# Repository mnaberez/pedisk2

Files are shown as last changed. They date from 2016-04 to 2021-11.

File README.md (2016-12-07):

# PEDISK II

This repository holds reverse engineering work on the
[PEDISK II](http://mikenaberezny.com/hardware/pet-cbm/microtech-pedisk-ii/) from CGRS Microtech,
a floppy disk controller for Commodore PET/CBM computers.

## Files

 - `rom_e800.bin` is a binary dump of the EPROM.

 - `rom_e800.asm` is a disassembly of it.

## Assemble

The `.asm` files can be assembled with the
[ACME](http://www.esw-heim.tu-clausthal.de/~marco/smorbrod/acme/)
assembler:

    $ acme -v1 --outfile test.bin pedisk2.asm

It should assemble a binary that is identical to the original.

## Credits

- Lee Davison did the initial disassembly of the ROM.
- Jim Oldfield provided the 5.25" PEDISK disks from which the DOS code was
  recovered.
- Mike Naberezny disassembled the 5.25" DOS code, adapted it for 8", and wrote
  the image tools.
- Steve Hirsch provided help and formatted 8" disks used for early testing.
- Josh Bensadon reverse engineered the original PCB and made the schematic.
- Steve Gray made the replica PCB layout and had boards manufactured.
- Mike Stein built the replica and provided help and input throughout.
- Bill Goble, the original designer of the PEDISK, found and donated the
  original manuals, schematics, source code, and master disks.

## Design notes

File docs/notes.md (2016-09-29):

PEDISK II Notes
===============

Drive Selection
---------------

The drive can be exercised from BASIC without using any of the PEDISK II's
ROM routines.  This is done by `POKE` and `PEEK` commands directly accessing
the FD1793 and the 74LS175 latch.  The drive must be selected before most
other commands will work.  

Select the first drive (drive 1):

    poke 59648,9 : rem write to $e900 latch (u7 74ls175)
                       bit 4 = fd1793 /dden (0=double density, 1=single)
                       bit 0 = drive 1 select

Deselect the drive:

    poke 59648,0

When the drive is selected, there will be an audible click as the head
load solenoid engages.  The activity LED on the front of the drive will
also turn on.  When deselected, the solenoid releases and the LED turns off.

Head Step
---------

Step out (decrease track, towards track 0):

    poke 59776,99 : rem write to $e980 fd1793 command register

Step in (increase track, towards track 76):

    poke 59776,67 : rem write to $e980 fd1793 command register

Do not step beyond track 76.  It will bump against the stop.

Random Seek
-----------

Restore (go to track 0):

    poke 59776,11 : rem write to $e980 fd1793 command register

Seek to a random track:

    poke 59779,t  : rem write to $e983 fd1793 data register
    poke 59776,27 : rem write to $e980 fd1793 command register

Show current track:

    print peek(59777) : rem read from $e981 fd1793 track register

Track Zero Sensor
-----------------

The track zero sensor is on pin 34 of the FD1793.  When the head is
positioned on track zero, pin 34 is low.  When it is not, pin 34
is high.

Bit 2 of the FD1793 status register is track zero status:

    print peek(59776) and 4 : rem read from $e980 fd1793 status register

Prints ``4`` when positioned on track zero, should print ``0``
when on any other track.

Write Protect Sensor
--------------------

The write protect sensor is on pin 36 of the FD1793.  When the notch is
covered, pin 36 is high.  When it is not, pin 36 is low.

Bit 6 of the FD1793 status register is write protect status:

    print peek(59776) and 64 : rem read from $e980 fd1793 status register

Prints ``64`` when notch is not covered, ``0`` when not is covered.

Index Hole Sensor
-----------------

The index hole sensor is on pin 35 of the FD1793.  When the drive is selected
(``sys 60320``) and a floppy is spinning, the line pulses.  When the drive
is not selected (``sys 60171``), or the floppy is not spinning, the line does
not pulse.

Disk Format
-----------

The PEDISK II model 877-1 uses an 8" single sided, soft sectored, single density
(FM) floppy disk. It has 77 tracks, 26 sectors per track, and a 128 byte sector
length.  It can hold about 250 KB.

8" double sided disks are not compatible because they have the index hole in
a different position than 8" single sided disks.  The PEDISK requires single
sided disks.  If a double sided disk is inserted, the index hole sensor will
not pulse, and the head load solenoid will not engage.

8" hard sectored disks are also not compatible.  The PEDISK requires soft
sectored disks.  If a hard sectored disk is inserted, the head load solenoid
will engage, but the format program will hang.

FD1793 pin 37 is ``/DDEN`` (``/DOUBLE DENSITY``) and should be low when double
density.  On the PEDISK II, pin 37 is high (single density).

FD1793 pin 24 is ``CLK`` (``CLOCK``).  According to the datasheet, it should
be 2.0 MHz for 8" drives.  On the PEDISK II, it measures 2.0 MHz on the
logic analyzer.

Midnite Software Gazette, Issue 11 (Feb/Mar 1983):
"PEDISK Model 877 is an 8" SD floppy disk system that uses the IBM 3740
 format ... Eight inch SD CPM (trademark of Digital Research) diskettes
 can also be read/written with the 877 system."

From the ROM:
 - Tracks: 77 ($EBD3)
 - Sectors Per Track: ($EC74)
 - Sector Length: 128 bytes ($ECCA)

Board Jumpers
-------------

Jumper W1 is ``8`` or ``5``.  This means 8" or 5.25".  When the jumpered
for ``8``, FD1793 pin 24 ``CLK`` measures 2.0 MHz on the logic analyzer.  When
jumpered for ``5``, ``CLK`` measures 1.0 MHz.  This matches what the datasheet
says ``CLK`` should be for 8" and 5.25" drives.

Jumper W2 is ``250`` or ``125``.  It is set to ``250``.  This is probably
the bit rate (kbits/sec).  For Single Density 8", the bit rate is 250
kbits/sec.  According to a [table](http://en.wikipedia.org/wiki/List_of_floppy_disk_formats),
all the 8" double density formats are 500 kbits/sec.  There is no
``500`` option on the PEDISK board.

Jumpers W3, W4, and W5 are unknown.  They are all open.

BASIC Wedge
-----------

Initialize the PEDISK II and it will attempt to load the DOS from disk:

    sys 59904

It should print the welcome banner:

    pedisk ii system
    cgrs microtech
    langhorne,pa.19047 c1981

After a short time, it will return to the ``ready.`` prompt.  If the DOS
can't be loaded from disk, a ``disk error`` message will be printed before
the prompt the prompt returns.  The BASIC wedge is not installed if the DOS
is not loaded.

Detect if the wedge is installed:

    print peek(121)

Prints ``76`` if installed or ``201`` if not installed.

All of the PEDISK II commands are loaded into RAM from the boot disk, with the
sole exception of ``!load``.  The ``!load`` command can be used even if the boot
disk can't be loaded.  However, the wedge must be force installed.

Force the wedge to install:

    sys 60159

Load a program:

    !load"foobar:0"

The filename (``foobar``) may be up to six characters.  The drive number
(``:0``) must be included or else a ``?syntax error`` will result.

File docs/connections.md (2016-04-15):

34-pin Floppy Drive Connector
-----------------------------

| PEDISK II 34-pin | 50-pin |Dir  |Siemens | Shugart | Micropolis | Notes |
|---:|---:|:---:|---:|---:|---:|:-----:|
| N/C | 2 | | | | | |
| N/C | 4 | | | | | |
| N/C | 6 | | | | | |
| N/C | 8 | | | | | |
| N/C | 10 | In  | 2SIDED | | | |
| N/C | 12 | Out | DCG | | | |
| N/C | 14 | Out | SIDE | | | |
| N/C | 16 | Out | IN USE | | | |
| N/C | 18 | Out | HLD | | | |
| 4 | 20 | In  | INDEX | (IN USE)| N/C | *1, 2*|
| 6 | 22 | In  | READY | SEL4 | READY | *3* |
| 8 | 24 | In  | (SECTOR) | INDEX | SEC/INDEX  | *1, 2*|
| 10 | 26 | Out | SEL1 | SEL1 | SEL1 | |
| 12 | 28 | Out | SEL2 | SEL2 | SEL2 | |
| N/C | 30 | Out | SEL3 | SEL3 | SEL3 | |
| 16 | 32 | Out | SEL4 | MOTOR | MOTOR | *4* |
| 18 | 34 | Out | DIRC | DIRC | DIRC | |
| 20 | 36 | Out | STEP | STEP | STEP | |
| 22 | 38 | Out | WDAT | WDAT | WDAT | |
| 24 | 40 | Out | WRITE | WGATE | WGATE | |
| 26 | 42 | In  | TRK00 | TRK00 | TRK00 | |
| 28 | 44 | In  | WPROT | WPROT | WPROT | |
| 30 | 46 | In  | RDATA | RDATA | RDATA | |
| 32 | 48 | Both| (SEP DAT)| HD SEL  | HD SEL | *1, 5*|
| N/C | 50 | In  | (SEP CLK)| RY/DC | SEL4 | *1* |

Notes:

1. `(XX)` is an optional signal that may not be installed on the drive.

2. PEDISK II always connects pins 4(20) and 8(24) in parallel.

3. PEDISK II is no-connect unless jumper W4 is installed.  If W4 is installed,
   the WD1793 gets the `READY` signal from the drive.

4. PEDISK II is no-connect unless jumper W3 is installed.  If W3 is installed,
   `MOTOR` is grounded (motor always on).

5. PEDISK II is no-connect unless jumper W5 is installed.  If W5 is installed,
   the PEDISK II can control `HD SEL` (Head Select).

Jumper Settings
---------------

| Jumper |5.25"  |8" | Description | Notes |
|---|---|---|---|:-----:|
| W1 250/125 |250 |250 | Select Bit Rate (kbits/sec) | |
| W2 5/8 |5 |8 | ??? | |
| W3 |Close  |Open | Grounds MOTOR | |
| W4 |Depends|Depends| Close for Micropolis drives with RDY | *1* |
| W5 |Close  |Open | Connects HD SELECT for 5.25" | &nbsp;|

Notes:

1. An 8" PEDISK II system was found with a Siemens FDD100-8 drive.  This drive
   has a `READY` signal on pin 6(22) but the PEDISK II was configured with W4
   open.  The system works in this configuration.

In addition to the jumpers above, the WD1793's `/DDEN` (Double Density Enable)
line must be set high for 8" (single density) or low for 5.25" (double
density).  `/DDEN` is controlled by pin 15 of the U7 latch.  The
firmware/software must be changed to set `/DDEN` appropriately.  Another option
would be to disconnect `/DDEN` from the latch and tie it permanently high
or low.

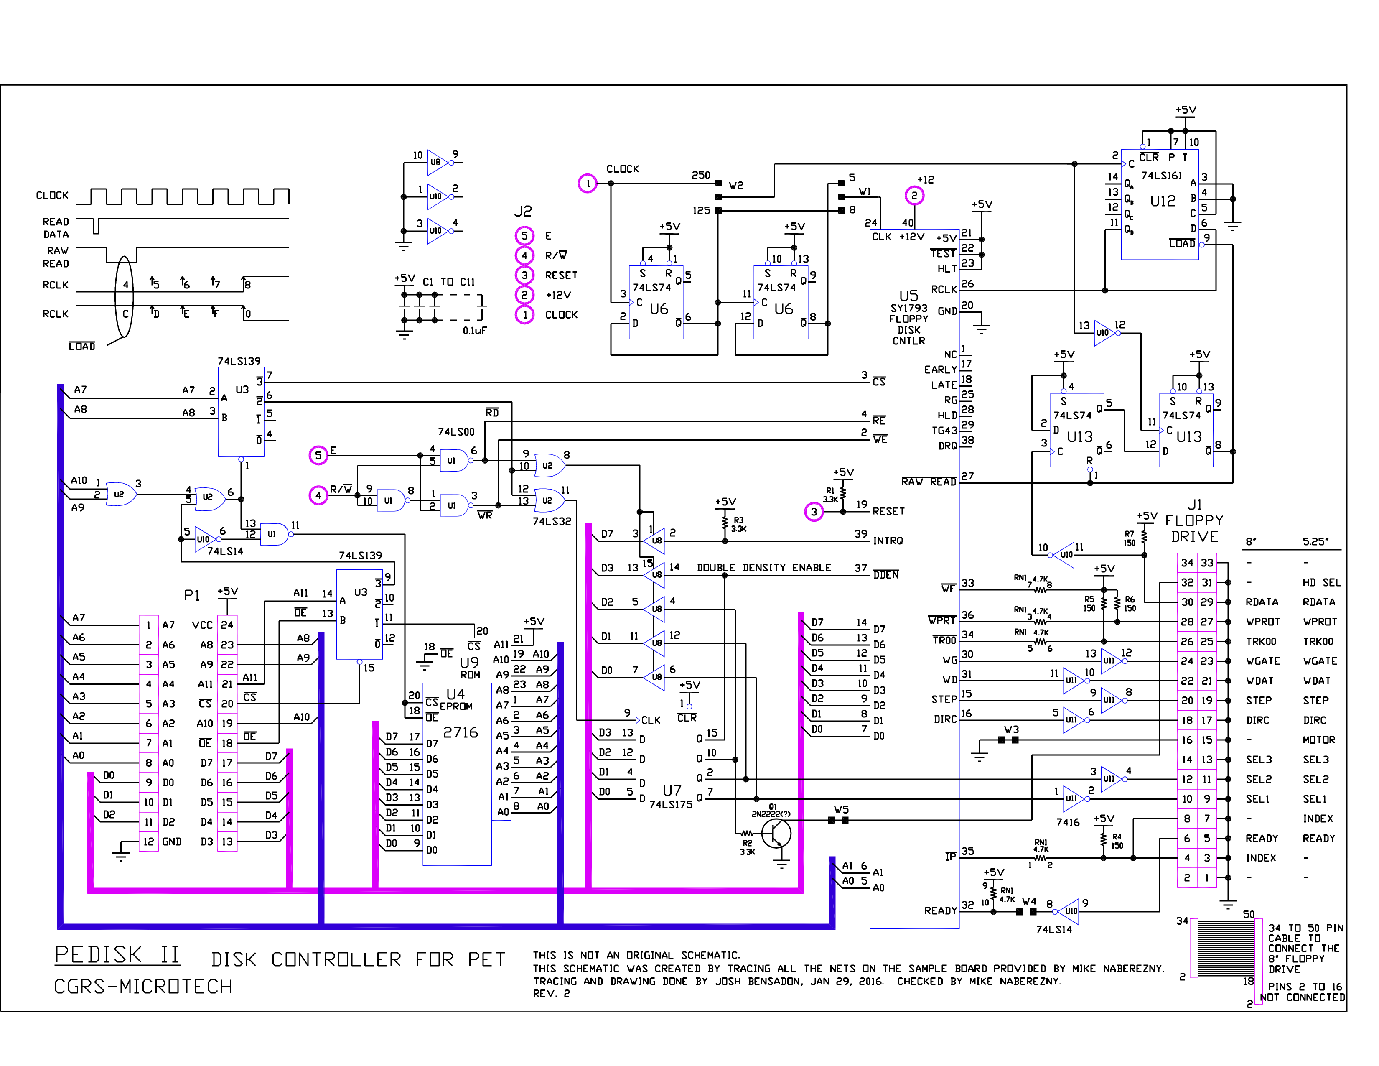
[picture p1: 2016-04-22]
docs/schematic.png

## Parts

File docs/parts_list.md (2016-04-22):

Parts List
----------

| Reference | Part |
|---|---|
| C1-11 | 0.1 uF |
| J1 | 34-pin Header |
| Q1 | 2N2222 (??) |
| R1, R2, R3, R7 | 3.3 K |
| R4, R5, R6 | 150 Ohm |
| RN1 | 4.7 K |
| U1 | 74LS00 |
| U2 | 74LS32 |
| U3 | 74LS139 |
| U4 | 2716 |
| U5 | WD1793 |
| U6 | 74LS74 |
| U7 | 74LS175 |
| U8 | 74367 |
| U9 | 901474-03 |
| U10 | 74LS14 |
| U11 | 7416 |
| U12 | 74LS161 |
| U13 | 74LS74 |
| W1, W2 | 3-pin Jumper Block |
| W3, W4, W5 | 2-pin Jumper Block |

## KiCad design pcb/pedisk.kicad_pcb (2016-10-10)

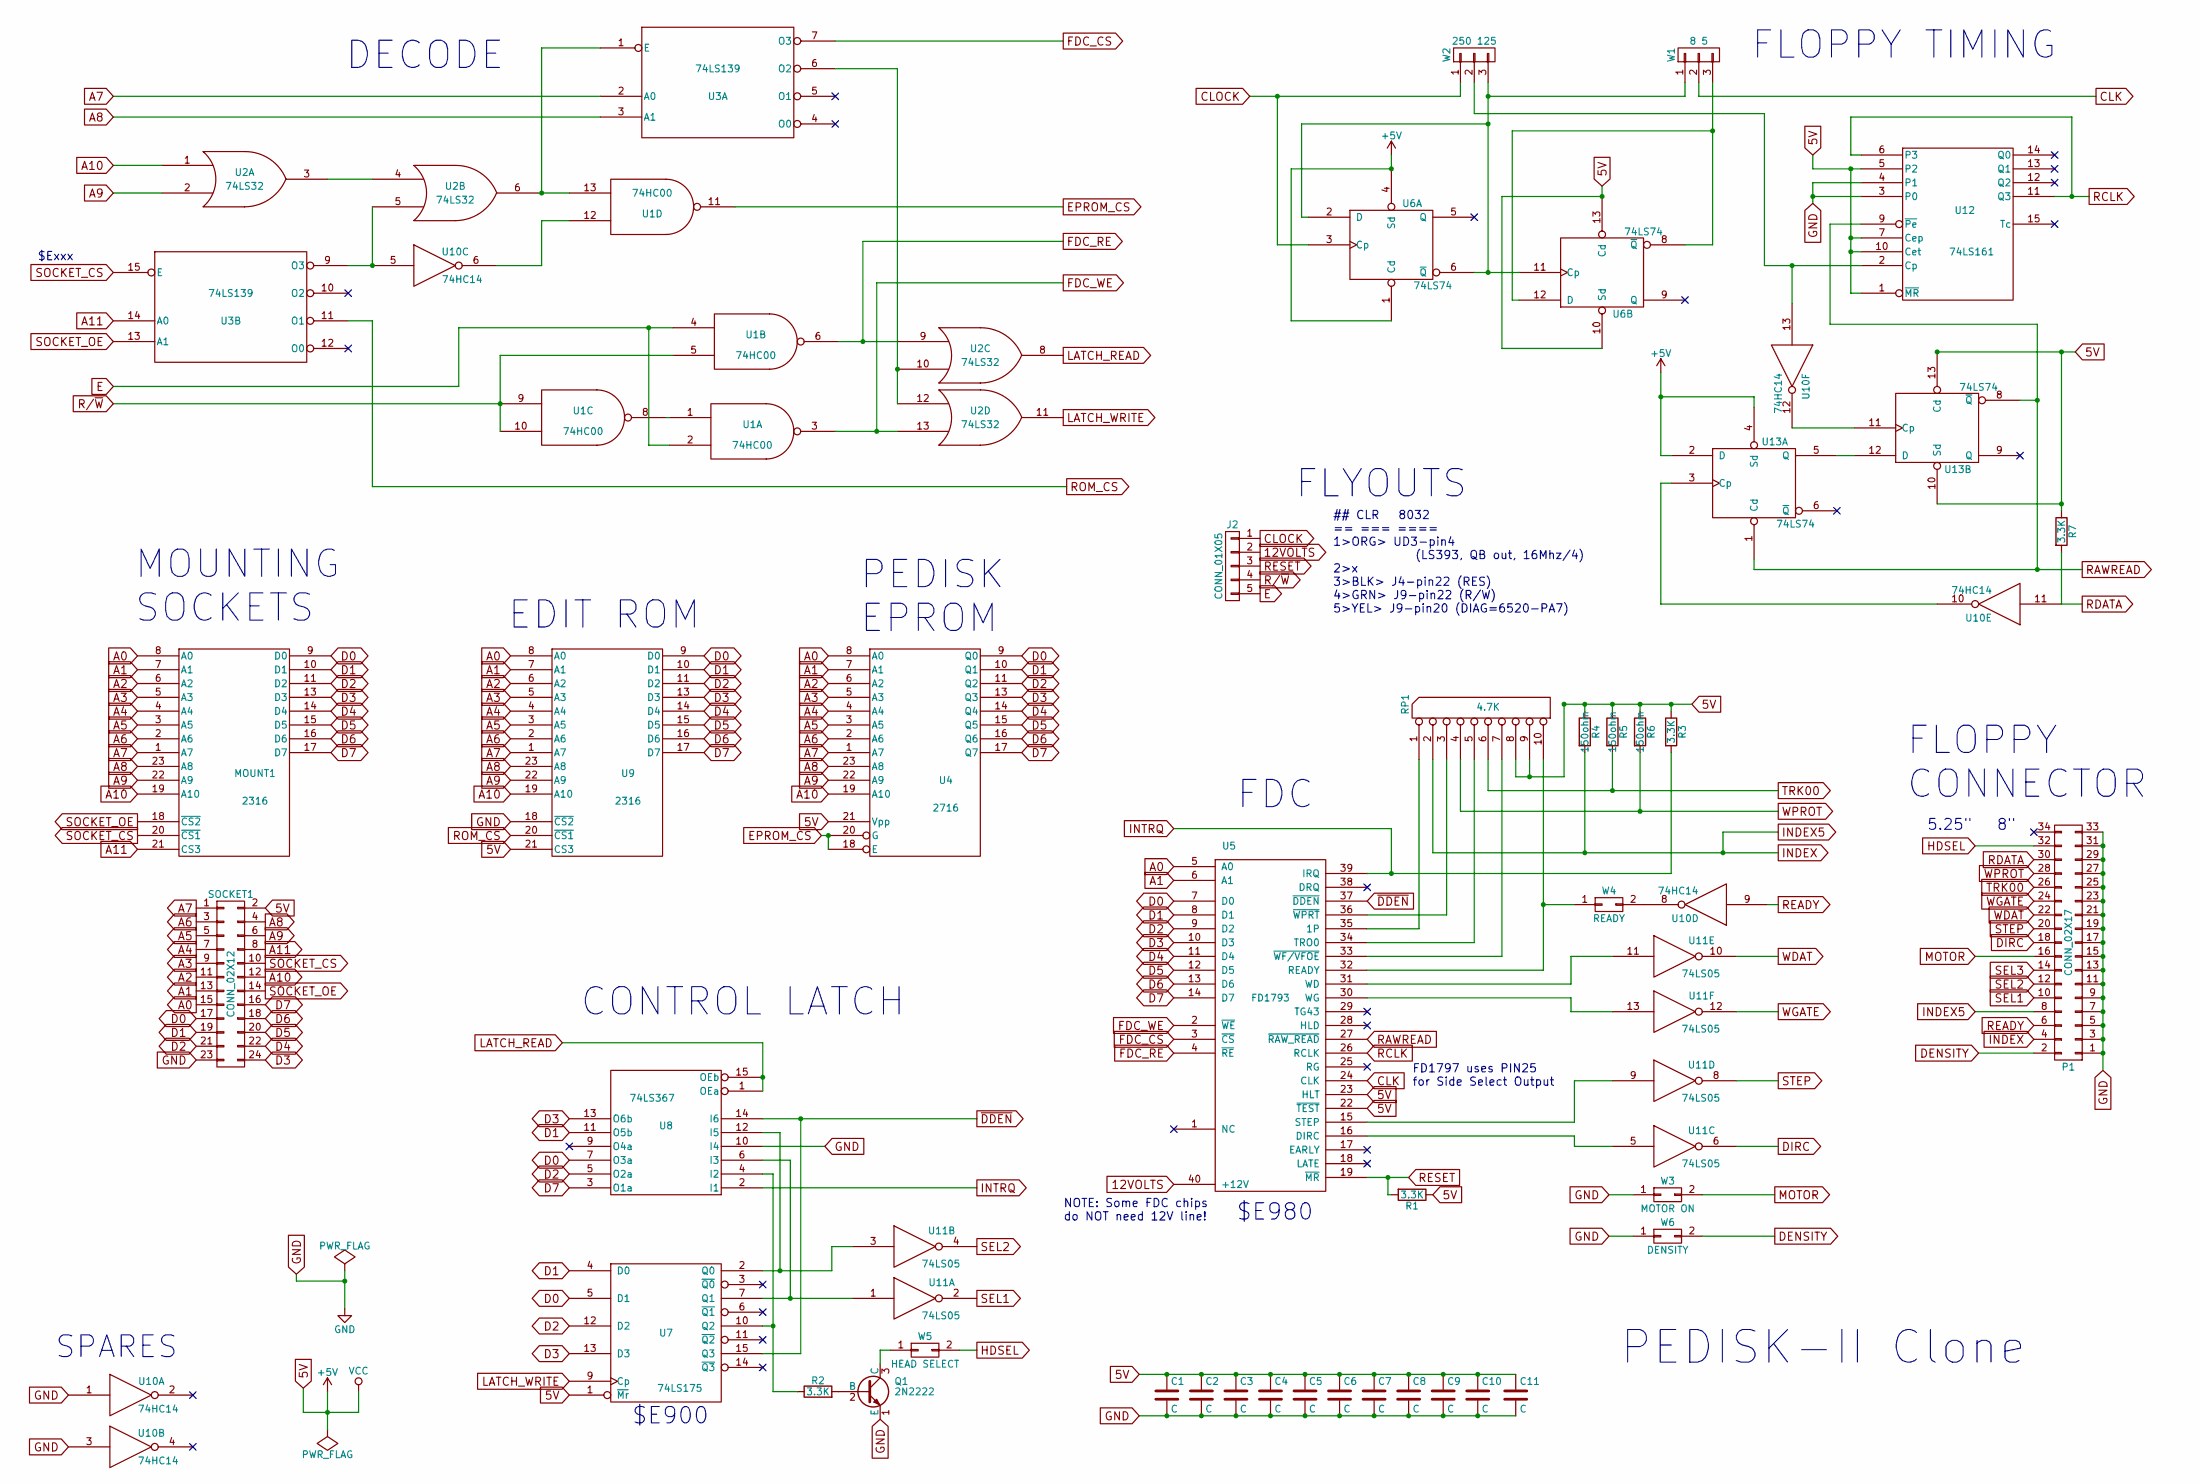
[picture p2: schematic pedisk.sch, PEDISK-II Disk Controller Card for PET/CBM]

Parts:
C1, C2, C3, C4, C5, C6, C7, C8, C9, C10, C11: C; C_Disc_D3_P2.5
J2: CONN_01X05; Pin_Header_Straight_1x05
MOUNT1: 2316; DIP-24_W15.24mm_LongPads
P1: CONN_02X17; IDC_Header_Straight_34pins
Q1: 2N2222; TO-92_Inline_Wide
R1, R2, R3, R7: 3.3K; Resistor_Horizontal_RM10mm
R4, R5, R6: 150ohm; Resistor_Horizontal_RM10mm
RP1: 4.7K; Resistor_Array_SIP9
SOCKET1: CONN_02X12; Pin_Header_Straight_2x12
U1: 74HC00; DIP-14_W7.62mm_LongPads
U2: 74LS32; DIP-14_W7.62mm_LongPads
U3: 74LS139; DIP-16_W7.62mm_LongPads
U4: 2716; DIP-24_W15.24mm_LongPads
U5: FD1793; DIP-40_W15.24mm_LongPads
U6, U13: 74LS74; DIP-14_W7.62mm_LongPads
U7: 74LS175; DIP-16_W7.62mm_LongPads
U8: 74LS367; DIP-16_W7.62mm_LongPads
U9: 2316; DIP-24_W15.24mm_LongPads
U10: 74HC14; DIP-14_W7.62mm_LongPads
U11: 74LS05; DIP-14_W7.62mm_LongPads
U12: 74LS161; DIP-16_W7.62mm_LongPads
W1: 8 5; Pin_Header_Straight_1x03
W2: 250 125; Pin_Header_Straight_1x03
W3: MOTOR ON; Pin_Header_Straight_2x01
W4: READY; Pin_Header_Straight_2x01
W5: HEAD SELECT; Pin_Header_Straight_2x01
W6: DENSITY; Pin_Header_Straight_2x01

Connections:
12VOLTS: J2.2, U5.40 (+12V)
A0: MOUNT1.8 (A0), SOCKET1.15, U4.8 (A0), U5.5 (A0), U9.8 (A0)
A1: MOUNT1.7 (A1), SOCKET1.13, U4.7 (A1), U5.6 (A1), U9.7 (A1)
A2: MOUNT1.6 (A2), SOCKET1.11, U4.6 (A2), U9.6 (A2)
A3: MOUNT1.5 (A3), SOCKET1.9, U4.5 (A3), U9.5 (A3)
A4: MOUNT1.4 (A4), SOCKET1.7, U4.4 (A4), U9.4 (A4)
A5: MOUNT1.3 (A5), SOCKET1.5, U4.3 (A5), U9.3 (A5)
A6: MOUNT1.2 (A6), SOCKET1.3, U4.2 (A6), U9.2 (A6)
A7: MOUNT1.1 (A7), SOCKET1.1, U3.2 (A0), U4.1 (A7), U9.1 (A7)
A8: MOUNT1.23 (A8), SOCKET1.4, U3.3 (A1), U4.23 (A8), U9.23 (A8)
A9: MOUNT1.22 (A9), SOCKET1.6, U2.2, U4.22 (A9), U9.22 (A9)
A10: MOUNT1.19 (A10), SOCKET1.12, U2.1, U4.19 (A10), U9.19 (A10)
A11: MOUNT1.21 (CS3), SOCKET1.8, U3.14 (A0)
CLK: U5.24 (CLK), W1.2
CLOCK: J2.1, U6.3 (Cp), W2.1
D0: MOUNT1.9 (D0), SOCKET1.17, U4.9 (Q0), U5.7 (D0), U7.5 (D1), U8.7 (O3a), U9.9 (D0)
D1: MOUNT1.10 (D1), SOCKET1.19, U4.10 (Q1), U5.8 (D1), U7.4 (D0), U8.11 (O5b), U9.10 (D1)
D2: MOUNT1.11 (D2), SOCKET1.21, U4.11 (Q2), U5.9 (D2), U7.12 (D2), U8.5 (O2a), U9.11 (D2)
D3: MOUNT1.13 (D3), SOCKET1.24, U4.13 (Q3), U5.10 (D3), U7.13 (D3), U8.13 (O6b), U9.13 (D3)
D4: MOUNT1.14 (D4), SOCKET1.22, U4.14 (Q4), U5.11 (D4), U9.14 (D4)
D5: MOUNT1.15 (D5), SOCKET1.20, U4.15 (Q5), U5.12 (D5), U9.15 (D5)
D6: MOUNT1.16 (D6), SOCKET1.18, U4.16 (Q6), U5.13 (D6), U9.16 (D6)
D7: MOUNT1.17 (D7), SOCKET1.16, U4.17 (Q7), U5.14 (D7), U8.3 (O1a), U9.17 (D7)
DENSITY: P1.2, W6.2
DIRC: P1.18, U11.6
E: J2.5, U1.2, U1.4
EPROM_CS: U1.11, U4.18 (E), U4.20 (G)
FDC_CS: U3.7 (O3), U5.3 (~CS)
FDC_RE: U1.6, U2.9, U5.4 (~RE)
FDC_WE: U1.3, U2.13, U5.2 (~WE)
GND: C1.2, C2.2, C3.2, C4.2, C5.2, C6.2, C7.2, C8.2, C9.2, C10.2, C11.2, MOUNT1.12 (GND), P1.1, P1.3, P1.5, P1.7, P1.9, P1.11, P1.13, P1.15, P1.17, P1.19, P1.21, P1.23, P1.25, P1.27, P1.29, P1.31, P1.33, Q1.1 (E), SOCKET1.23, U1.7 (GND), U2.7 (GND), U3.8 (GND), U4.12 (GND), U5.20 (GND), U6.7 (GND), U7.8 (GND), U8.8 (GND), U8.10 (I4), U9.12 (GND), U9.18 (~CS2), U10.1, U10.3, U10.7 (GND), U11.7 (GND), U12.3 (P0), U12.4 (P1), U12.8 (GND), U13.7 (GND), W3.1, W6.1
HDSEL: P1.32, W5.2
INDEX: P1.4, P1.8, R4.2, RP1.2
INTRQ: R3.2, U5.39 (IRQ), U8.2 (I1)
LATCH_READ: U2.8, U8.1 (OEa), U8.15 (OEb)
LATCH_WRITE: U2.11, U7.9 (Cp)
MOTOR: P1.16, W3.2
unnamed: Q1.2 (B), R2.2
unnamed: Q1.3 (C), W5.1
unnamed: R2.1, U7.10 (Q2), U8.4 (I2)
unnamed: RP1.1 (COM), U5.35 (1P)
unnamed: RP1.3, U5.36 (~WPRT)
unnamed: RP1.5, U5.34 (TRO0)
unnamed: RP1.7, U5.33 (~WF/VFOE)
unnamed: RP1.10, U5.32 (READY), W4.1
unnamed: U1.1, U1.8
unnamed: U1.12, U10.6
unnamed: U1.13, U2.6, U3.1 (E)
unnamed: U2.3, U2.4
unnamed: U2.10, U2.12, U3.6 (O2)
unnamed: U6.2 (D), U6.6 (~Q), U6.11 (Cp), W1.1, W2.3
unnamed: U6.8 (~Q), U6.12 (D), W1.3
unnamed: U2.5, U3.9 (O3), U10.5
unnamed: U10.8, W4.2
unnamed: U10.10, U13.3 (Cp)
unnamed: U10.12, U13.11 (Cp)
unnamed: U10.13, U12.2 (Cp), W2.2
unnamed: U7.7 (Q1), U8.6 (I3), U11.1
unnamed: U7.2 (Q0), U8.12 (I5), U11.3
unnamed: U5.16 (DIRC), U11.5
unnamed: U5.15 (STEP), U11.9
unnamed: U5.31 (WD), U11.11
unnamed: U5.30 (WG), U11.13
unnamed: U13.5 (Q), U13.12 (D)
R/~W: J2.4, U1.5, U1.9, U1.10
RAWREAD: U5.27 (~RAW_READ), U12.9 (~Pe), U13.1 (Cd), U13.8 (~Q)
RCLK: U5.26 (RCLK), U12.6 (P3), U12.11 (Q3)
RDATA: P1.30, R7.2, U10.11
READY: P1.6, U10.9
ROM_CS: U3.11 (O1), U9.20 (~CS1)
SEL1: P1.10, U11.2
SEL2: P1.12, U11.4
SEL3: P1.14
SOCKET_CS: MOUNT1.20 (~CS1), SOCKET1.10, U3.15 (E)
SOCKET_OE: MOUNT1.18 (~CS2), SOCKET1.14, U3.13 (A1)
STEP: P1.20, U11.8
TRK00: P1.26, R5.2, RP1.6
WDAT: P1.22, U11.10
WGATE: P1.24, U11.12
WPROT: P1.28, R6.2, RP1.4
~DDEN: U5.37 (~DDEN), U7.15 (Q3), U8.14 (I6)

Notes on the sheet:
SPARES
FLYOUTS
MOUNTING SOCKETS
PEDISK EPROM
EDIT ROM
DECODE
CONTROL LATCH
FDC
FLOPPY TIMING
FLOPPY CONNECTOR
PEDISK-II Clone
5.25" 8"
## CLR 8032 == === ==== 1>ORG> UD3-pin4 (LS393, QB out, 16Mhz/4) 2>x 3>BLK> J4-pin22 (RES) 4>GRN> J9-pin22 (R/W) 5>YEL> J9-pin20 (DIAG=6520-PA7)
$E980
$E900
$Exxx
NOTE: Some FDC chips do NOT need 12V line!
FD1797 uses PIN25 for Side Select Output

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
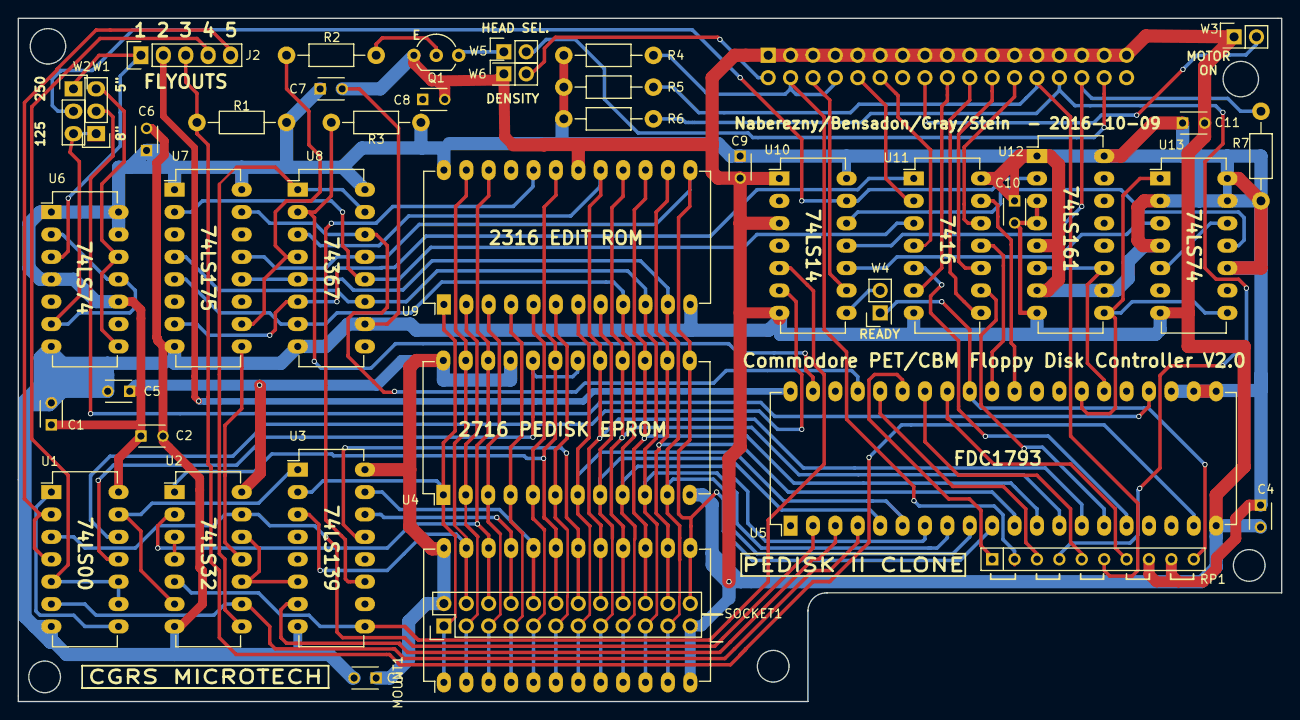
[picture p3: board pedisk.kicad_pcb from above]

Board: 2 copper layers, 143.3 x 77.5 mm, 43 parts (1 on the bottom side), 82 nets.

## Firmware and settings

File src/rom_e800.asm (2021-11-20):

;This is a bit correct disassembly of the PEDISK II ROM
;Based on work by Lee Davison 2013-07-04

latch        = $e900    ;Latch (U7 75LS175)
                        ;  bit function
                        ;  === ======
                        ;  7   WD1793 INTRQ (read only)
                        ;  6-4 unused
                        ;  3   WD1793 /DDEN (0=double density, 1=single)
                        ;  2   drive 3 select
                        ;  1   drive 2 select
                        ;  0   drive 1 select

fdc          = $e980    ;WD1793 Floppy Disk Controller
fdc_cmdst    = fdc+0    ;  Command/status register
fdc_track    = fdc+1    ;  Track register
fdc_sector   = fdc+2    ;  Sector register
fdc_data     = fdc+3    ;  Data register

;WD1793 Floppy Disk Controller
;
;    Command           b7 b6 b5 b4 b3 b2 b1 b0
;I   Restore           0  0  0  0  h  V  r1 r0
;I   Seek              0  0  0  1  h  V  r1 r0
;I   Step              0  0  1  T  h  V  r1 r0
;I   Step-In           0  1  0  T  h  V  r1 r0
;I   Step-Out          0  1  1  T  h  V  r1 r0
;II  Read Sector       1  0  0  m  S  E  C  0
;II  Write Sector      1  0  1  m  S  E  C  a0
;III Read Address      1  1  0  0  0  E  0  0
;III Read Track        1  1  1  0  0  E  0  0
;III Write Track       1  1  1  1  0  E  0  0
;IV  Force Interrupt   1  1  0  1  i3 i2 i1 i0
;
;   r1 r0  Stepping Motor Rate
;    1  1   30 ms
;    1  0   20 ms
;    0  1   12 ms
;    0  0   6 ms
;     V      Track Number Verify Flag (0: no verify, 1: verify on dest track)
;     h      Head Load Flag (1: load head at beginning, 0: unload head)
;       T      Track Update Flag (0: no update, 1: update Track Register)
;       a0     Data Address Mark (0: FB, 1: F8 (deleted DAM))
;       C      Side Compare Flag (0: disable side compare, 1: enable side comp)
;       E      15 ms delay (0: no 15ms delay, 1: 15 ms delay)
;       S      Side Compare Flag (0: compare for side 0, 1: compare for side 1)
;       m      Multiple Record Flag (0: single record, 1: multiple records)
;           i3 i2 i1 i0    Interrupt Condition Flags
;              i3-i0 = 0 Terminate with no interrupt (INTRQ)
;                    i3 = 1 Immediate interrupt, requires a reset
;                    i2 = 1 Index pulse
;                    i1 = 1 Ready to not ready transition
;                    i0 = 1 Not ready to ready transition
;
;status bits         bit when 1
;                    === ======
;                     7  drive not ready
;                     6  write protect
;                     5  write error
;                     4  seek error
;                     3  crc error
;                     2  track zero/lost data
;                     1  data request
;                     0  busy

;In the zero page locations below, ** indicates the PEDISK destroys
;a location that is used for some other purpose by CBM BASIC 4.

valtyp      = $07       ;Data type of value: 0=numeric, $ff=string
dir_ptr     = $22       ;Pointer: PEDISK directory **
fname_ptr   = $24       ;Pointer: PEDISK filename **
hex_save_a  = $26       ;PEDISK temporarily saves A during hex conversion **
edit_pos    = $27       ;PEDISK memory editor position on current line **
txttab      = $28       ;Pointer: Start of BASIC text
vartab      = $2a       ;Pointer: Start of BASIC variables
fretop      = $30       ;Pointer: Bottom of string storage
frespc      = $32       ;Pointer: Utility string
memsiz      = $34       ;Pointer: Highest address used by BASIC
curlin      = $36       ;Current BASIC line number (2 bytes)
varpnt      = $44       ;Pointer: Current BASIC variable
open_track  = $56       ;Next track open for a new file **
open_sector = $57       ;Next sector open for a new file **
edit_ptr    = $66       ;Pointer: PEDISK current address of memory editor **
puts_ptr    = $6c       ;Pointer: PEDISK string to print for puts **
chrget      = $70       ;Subroutine: Get Next Byte of BASIC Text
chrgot      = $76       ;Subroutine: Get the Same Byte of BASIC Text again
txtptr      = $77       ;Pointer: Current Byte of BASIC Text
target_ptr  = $b7       ;Pointer: PEDISK target address for memory ops **
dos         = $7800     ;Base address for the RAM-resident portion
dos_save    = dos+$0000 ;Entry point for !SAVE
dos_open    = dos+$0003 ;Entry point for !OPEN
dos_close   = dos+$0006 ;Entry point for !CLOSE
dos_input   = dos+$0009 ;Entry point for !INPUT
dos_print   = dos+$000c ;Entry point for !PRINT
dos_run     = dos+$000f ;Entry point for !RUN (load and run)
dos_sys     = dos+$0012 ;Entry point for !SYS (PDOS disk monitor)
dos_list    = dos+$0015 ;Entry point for !LIST (directory)
dos_monitor = dos+$0200 ;Base address of PDOS monitor overlay (!SYS prompt)
copy_sector = dos+$0600 ;128 bytes for sector, used only by copy disk overlay
file_infos  = dos+$0680 ;4 buffers of 32 bytes each for tracking open files
dir_sector  = dos+$0700 ;128 bytes for directory sector used by find_file
save_char   = dos+$0788 ;Temp storage for char read at PEDISK monitor prompt
wedge_x     = dos+$0789 ;Temp storage for X register used by the wedge
wedge_y     = dos+$078a ;Temp storage for Y register used by the wedge
wedge_sp    = dos+$078b ;Temp storage for stack pointer used by the wedge
retries     = dos+$078c ;Counts down retries remaining for disk operations
save_a      = dos+$078d ;Temp storage for A reg used by several routines
save_x      = dos+$078e ;Temp storage for X reg used by several routines
status_mask = dos+$0790 ;Mask to apply when checking WD1793 status register
drive_sel   = dos+$0791 ;Drive select bit pattern to write to the latch
track       = dos+$0792 ;Track number to write to WD1793 (0-76 or $00-4c)
sector      = dos+$0793 ;Sector number to write to WD1793 (1-26 or $01-1a)
status      = dos+$0794 ;Last status byte read from WD1793 (no masking)
command     = dos+$0795 ;Last command byte written to WD1793
num_sectors = dos+$0796 ;Number of sectors to read or write
tmp_7f97    = dos+$0797 ;Temp byte used by dos+$0400 overlays for misc things
tmp_7f98    = dos+$0797 ;Temp byte used by dos+$0400 overlays for misc things
copy_track  = dos+$0799 ;Current track number, used only by copy disk overlay
tmp_7f9a    = dos+$079a ;Temp byte used by dos+$0400 overlays for misc things
dir_entry   = dos+$07a0 ;32 bytes: a dir entry (first 16) or file info (32)
drive_sel_f = dos+$07b1 ;Drive select bit pattern parsed from a filename
wedge_stack = dos+$07e0 ;32 bytes for preserving the stack used by the wedge
ptrget      = $c12b     ;BASIC Find a variable
wrob        = $d722     ;Monitor Write byte in A out as a two digit hex
hexit       = $d78d     ;Monitor Evaluate char in A to a hex nibble
chrout      = $ffd2     ;KERNAL Send a char to the current output device
getin       = $ffe4     ;KERNAL Read a char from the current input device
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

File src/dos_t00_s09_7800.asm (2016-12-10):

latch        = $e900    ;Drive Select Latch

;In the zero page locations below, ** indicates the PEDISK destroys
;a location that is used for some other purpose by CBM BASIC 4.

valtyp      = $07       ;Data type of value: 0=numeric, $ff=string
intflg      = $08       ;Type of number: 0=floating point, $80=integer
linnum      = $11       ;2 byte integer (usually a line number) from linget
dir_ptr     = $22       ;Pointer: PEDISK directory **
hex_save_a  = $26       ;PEDISK temporarily saves A during hex conversion **
edit_pos    = $27       ;PEDISK memory editor position on current line **
txttab      = $28       ;Pointer: Start of BASIC text
vartab      = $2a       ;Pointer: Start of BASIC variables
varpnt      = $44       ;Pointer: Current BASIC variable
open_track  = $56       ;Next track open for a new file **
open_sector = $57       ;Next sector open for a new file **
tmp_track   = $58       ;TODO seems to hold a track
tmp_sector  = $59       ;TODO seems to hold a sector
filesize    = $58       ;2 byte file size, shared with tmp_track/tmp_sector
edit_ptr    = $66       ;Pointer: PEDISK current address of memory editor **
chrget      = $70       ;Subroutine: Get Next Byte of BASIC Text (patched)
txtptr      = $77       ;Pointer: Current Byte of BASIC Text
target_ptr  = $b7       ;Pointer: PEDISK target address for memory ops **

dos         = $7800     ;Base address for the RAM-resident portion
file_infos  = dos+$0680 ;4 buffers of 32 bytes each for tracking open files
dir_sector  = dos+$0700 ;128 bytes for directory sector used by find_file
wedge_x     = dos+$0789 ;Temp storage for X register used by the wedge
wedge_y     = dos+$078a ;Temp storage for Y register used by the wedge
wedge_sp    = dos+$078b ;Temp storage for stack pointer used by the wedge
file_num    = dos+$078f ;File number (0-3) of currently open file
drive_sel   = dos+$0791 ;Drive select bit pattern to write to the latch
track       = dos+$0792 ;Track number to write to WD1793 (0-76 or $00-4c)
sector      = dos+$0793 ;Sector number to write to WD1793 (1-26 or $01-1a)
num_sectors = dos+$0796 ;Number of sectors to read or write
dir_entry   = dos+$07a0 ;32 bytes: a dir entry (first 16) or file info (32)
wedge_stack = dos+$07e0 ;32 bytes for preserving the stack used by the wedge
drive_sel_f = dos+$07b1 ;Drive select bit pattern parsed from a filename
fi_pos      = dos+$07b2 ;2 bytes for record position used with FI% variable
fc_error    = dos+$07b5 ;Error code that will be set in FC% variable
m_7fba_track  = dos+$07ba ;TODO seems to hold a track
m_7fbb_sector = dos+$07bb ;TODO seems to hold a sector
m_7fbc_track  = dos+$07bc ;TODO seems to hold a track
m_7fbd_sector = dos+$07bd ;TODO seems to hold a sector
linget      = $b8f6     ;BASIC Fetch integer (usually a line number)
ptrget      = $c12b     ;BASIC Find a variable

check_colon    = $EA44
deselect_drive = $EB0B
restore        = $EB5E
put_spc        = $EB7A
put_spc_hex    = $EB7F
put_hex_byte   = $EB84
disk_error     = $EC96
read_a_sector  = $ECDF
read_sectors   = $ECE4
write_a_sector = $ED3A
write_sectors  = $ED3F
find_file      = $EE33
load_file      = $EE9E
get_char_w_stop= $EF59
puts           = $EFE7
chrout         = $FFD2

;Error codes for "disk error" message (all others in the ROM)
e_exists       = $05 ;File Exists
e_unknown_06   = $06 ;TODO Unknown

;Error codes for FC%
f_ok           = $00 ;OK
f_not_open     = $07 ;File not open
f_not_string   = $09 ;Variable is not a string
f_out_of_space = $2B ;Not enough space left on disk to create file
f_already_open = $30 ;File already open
f_too_many     = $31 ;Too many open files
f_bad_filename = $32 ;Bad filename (file exists or file not found)
f_len_float    = $34 ;LEN argument is a float
f_len_not_num  = $35 ;LEN argument not numeric
f_unknown_ff   = $ff ;TODO Unknown

    *=dos

dos_save:   jmp _dos_save   ;Perform !SAVE
dos_open:   jmp _dos_open   ;Perform !OPEN
dos_close:  jmp _dos_close  ;Perform !CLOSE
dos_input:  jmp _dos_input  ;Perform !INPUT
dos_print:  jmp _dos_print  ;Perform !PRINT
dos_run:    jmp _dos_run    ;Perform !RUN
dos_sys:    jmp _dos_sys    ;Perform !SYS
dos_list:   jmp _dos_list   ;Perform !LIST

save_from_basic:
;TODO Implements !SAVE command; _dos_save jumps here immediately
    lda vartab
    sec
    sbc txttab
    sta dir_entry+$06   ;Save file size low byte in dir entry
    sta filesize        ;Save file size low byte to calculate sector count

    lda vartab+1
    sbc txttab+1
    sta filesize+1      ;Save file size high byte to calculate sector count
    sta dir_entry+$07   ;Save file size high byte in dir entry

    lda txttab
    sta dir_entry+$08   ;Save load address low byte in dir entry

    lda txttab+1
    sta dir_entry+$09   ;Save load address high byte in dir entry

    jsr calc_n_sectors  ;Calculate num_sectors from filesize
    lda num_sectors
    sta dir_entry+$0e   ;Save file sector count low byte in dir entry

    lda #$00
    sta dir_entry+$0f   ;Save file sector count high byte in dir entry

    lda #$03            ;Type 3 = BASIC program
    sta dir_entry+$0a   ;Save file type in dir entry

    jsr find_file
    tax
    bmi save_done       ;Branch if a disk error occurred
    bne l_7857          ;Branch if the file was not found

    lda #e_exists       ;Set error code $05, file exists error
save_error:
    jsr disk_error      ;Print error msg, FDC restore cmd, deselect drive
    bne save_done       ;Branch always

l_7857:
;TODO Monitor command "S" (save file) jumps here to perform the save
;
    lda #$00
    sta dir_entry+$0b   ;TODO ??

    jsr l_78a2
    bne save_done       ;Branch if an error occurred
    lda fc_error
    beq l_786a          ;Branch if no error

    lda #e_unknown_06   ;A = 6, TODO error number for ??
    bne save_error      ;Branch always

l_786a:
    lda dir_entry+$08   ;File load address low byte
    sta target_ptr

    lda dir_entry+$09   ;File load address high byte
    sta target_ptr+1

    lda open_track
    sta track

    lda open_sector
    sta sector

    lda dir_entry+$0e   ;File sector count low byte
    sta num_sectors

    jsr write_sectors
    bne save_done       ;Branch if a disk error occurred

    ;Deselect drives and stop motors
    lda #$00            ;TODO disk conversion: this code always sets /DDEN=0
                        ;Bit 3 = WD1793 /DDEN=0 (double density mode)
                        ;All other bits off = deselect drives, stop motors
    sta latch

    lda #$00
save_done:
    rts

calc_n_sectors:
;TODO seems to calculate num_sectors from filesize
    lda filesize        ;Get file size low byte
    clc
    adc #$7F            ;$7F = 128 byte sector - 1
    bcc l_789a
    inc filesize+1      ;Get file size high byte
l_789a:
    asl ;a
    lda filesize+1      ;Get file size high byte
    rol ;a
    sta num_sectors
    rts
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

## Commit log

2013-07-03 Convert to ACME assembler format
2013-07-06 Add labels for print routines
2013-07-07 Add labels for track, sector, command, and status
2015-01-11 Fix off-by-one error in track comment
2015-01-25 Add DOS code from track 0, sectors 9-21
2015-01-31 Add labels for track, sector, status
2015-02-04 Found RAM locations for next open track and sector
2015-02-11 Found possible sectors per track constant
2015-02-13 Found sectors per track constant
2015-02-15 Found latch, drive_sel, track, sector, num_sectors
2015-02-15 Found possible track count constant
2015-02-15 Found possible track and sector constants
2015-02-15 Fix description of menu option "L"
    [dos_t00_s09_7800.asm]
2015-02-16 Assemble all files on Travis
2015-02-16 Fix equates for many PEDISK ROM locations
    [dos_t00_s09_7800.asm]
2015-02-16 Replace $77/78 with txtptr
    [dos_t00_s09_7800.asm]
2015-02-16 Replace $44 with varpnt
    [dos_t00_s09_7800.asm]
2015-02-16 Replace $66 with edit_ptr
    [dos_t00_s09_7800.asm]
2015-02-16 Replace $22 with dir_ptr
    [dos_t00_s09_7800.asm]
2015-02-16 Replace $B7 with target_ptr
    [dos_t00_s09_7800.asm]
2015-02-16 Replace $26 with hex_save_a
    [dos_t00_s09_7800.asm]
2015-02-16 Replace LC12B with ptrget
    [dos_t00_s09_7800.asm]
2015-02-17 Found print calls
2015-02-18 Add labels for disk and track subroutines
2015-02-20 Fix equates for ROM, add equates for common RAM
    [dos_t00_s22_7a00.asm]
2015-02-21 Fix disassembly of JSR $7818
    [dos_t00_s09_7800.asm]
2015-02-21 Replace $7BED with restore-1
    [dos_t00_s22_7a00.asm]
2015-02-21 Replace $7FB1 with drive_sel_f
    [dos_t00_s09_7800.asm, dos_t00_s22_7a00.asm]
2015-02-22 Replace LB8F6 with linget
    [dos_t00_s09_7800.asm]
2015-02-22 Replace L7AD1 with input_device
    [dos_t00_s22_7a00.asm]
2015-02-22 Replace $7e80 with buf_1
    [dos_t00_s09_7800.asm]
2015-02-22 Replace $7ee0 with buf_4
    [dos_t00_s09_7800.asm]
2015-02-22 Replace $7f00 with dir_sector
    [dos_t00_s09_7800.asm]
2015-02-22 Use equates for track, sector, drive_sel
2015-02-22 Add equates for RAM locations, add comments to program flow
2015-02-22 Fix addresses that are not filename related
    [dos_t00_s22_7a00.asm]
2015-02-22 Replace $ea2f with drive_selects
    [dos_t00_s22_7a00.asm]
2015-02-22 Add labels and comments to program flow
2015-02-22 Replace $e900 with latch
    [dos_t00_s09_7800.asm]
2015-02-23 Add note that BASIC shortcuts can be used
    [rom_e800.asm]
2015-02-23 Fix location of dos_stop
    [dos_t00_s09_7800.asm]
2015-02-23 Replace $7800 with dos_stop
    [dos_t00_s09_7800.asm]
2015-02-23 Replace $7fe0 with wedge_stack
    [dos_t00_s09_7800.asm]
2015-02-23 Found two additional error codes
    [dos_t00_s09_7800.asm]
2015-02-23 Add error info for select_drive, seek_track, find_file, load_file
    [rom_e800.asm]
2015-02-24 Add comments to find_file and load_file error handling
    [dos_t00_s09_7800.asm, dos_t00_s22_7a00.asm]
2015-02-24 Add comments to read/write sector error handling
    [dos_t00_s09_7800.asm, rom_e800.asm]
2015-02-24 Replace $11/12 with linnum
    [dos_t00_s09_7800.asm]
2015-02-24 Found routine that prints filename
2015-02-24 Fix description of used file entry count
    [rom_e800.asm]
2015-02-25 Found number of used entries and next open track/sector
2015-02-25 Replace $07 with valtyp
    [dos_t00_s09_7800.asm]
2015-02-25 Replace entry_addr/start_addr with dir_entry offsets
    [dos_t00_s09_7800.asm]
2015-02-25 Fix description of find_file calling params
    [rom_e800.asm]
2015-02-26 Add description of disk error message
    [rom_e800.asm]
2015-02-26 Found file exists error code
    [dos_t00_s09_7800.asm, rom_e800.asm]
2015-02-27 Found format track data sequence
2015-02-28 Fix description of track seek
2015-02-28 Print "FORMAT TRACK" before each track, not after
2015-02-28 Verify by reading from first and last track after format
2015-03-02 Add labels to program flow
2015-03-02 Found current track number during copy
2015-03-03 Replace $7b59 with L7B59
    [dos_t00_s09_7800.asm]
2015-03-06 Clarify that head load solenoid may not only be 8"
2015-03-12 Assemble format.asm on Travis
2015-04-06 Found usage for !OPEN, !CLOSE, !PRINT, !INPUT Issue 2 of the PEDISK newsletter has a program listing that shows these commands in use.
    [dos_t00_s09_7800.asm]
2015-04-07 Found possible error exit
    [dos_t00_s09_7800.asm]
2015-04-07 Found basics of record handling for !PRINT and !INPUT
2015-04-08 Found error codes set in FC% variable
    [dos_t00_s09_7800.asm]
2015-04-08 Found error handler for sequential commands
    [dos_t00_s09_7800.asm]
2015-04-10 Found FC% error codes for !OPEN
    [dos_t00_s09_7800.asm]
2015-04-12 Found error code for file already open
    [dos_t00_s09_7800.asm]
2015-04-12 Found error code for file not open
    [dos_t00_s09_7800.asm]
2015-04-12 Found error code for too many open files
    [dos_t00_s09_7800.asm]
2015-04-12 Fix description of find_file return value
    [dos_t00_s09_7800.asm]
2015-04-13 Replace $7BE9 with label
    [dos_t00_s09_7800.asm]
2015-04-13 Found error code for position out of range
    [dos_t00_s09_7800.asm]
2015-04-14 Fix usage of POS keyword
    [dos_t00_s09_7800.asm]
2015-04-14 Found FC% error code for OK
    [dos_t00_s09_7800.asm]
2015-04-26 Clarify error result for read/write/seek
    [rom_e800.asm]
2015-11-16 Add method to find next available track/sector
2015-11-17 Combine writes for track and sector
2015-11-17 Move reading track/sector above validations
2015-11-22 Print complete directory information
2015-11-25 Move track/sector validation and counting to DiskImage
2015-11-29 Move assembly and image creation into functions
2015-11-29 Shorten print_filename by using Y register
2015-11-29 Allow using device numbers other than 8
2015-11-29 Check for error after writing PEDISK track
2016-04-12 Add schematic drawn by Josh Bensadon
2016-04-13 Mark no-connects on PEDISK connector
2016-04-15 Correct drive pinouts and resistors on schematic
2016-04-15 Use the same names as the schematic
2016-04-16 Fix U12 pin 10 and add jumper W3
2016-04-22 Update schematic with changes from Josh Bensadon
2016-09-29 Move assembly sources to src/
2016-09-29 Use literals for printable chars
2016-09-30 Sort track files when writing to image
2016-10-07 Print more granular status messages
2016-10-08 Found track and sector storage
2016-10-09 Found more track and sector locations, add comments
2016-10-09 Fix size of buffer at dir_entry
    [dos_t00_s09_7800.asm, rom_e800.asm]
2016-10-10 Fix description of handle_filename
    [dos_t00_s09_7800.asm]
2016-10-10 Add KiCad extensions to .gitattributes
2016-10-10 Added Kicad files for PCB
    This is an updated version of the PCB design with modified mounting,
    some components moved slightly, updated labelling and additional jumper.
    [pedisk.kicad_pcb, pedisk.sch]
2016-10-11 Add constants for FC% error codes
    [dos_t00_s09_7800.asm]
2016-10-16 Make boot disk by assembling source files
2016-10-17 Print "finished ok" after all tracks are written
2016-10-23 tester.bas - fix range check for print
    change "9" to ":"
2016-12-06 Add "quad density" (80 track) image file support
2016-12-11 Add support for 40 track FM disk images
2021-11-20 Fix description of wedge installation
    [rom_e800.asm]
